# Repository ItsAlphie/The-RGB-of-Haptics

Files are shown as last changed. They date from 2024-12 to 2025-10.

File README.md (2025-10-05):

# The RGB of Haptics: The Impact of Haptic Primary Colours on Texture Perception for Extended Reality
## What's this project about?
This repository contains the code and framework developed for our Master's thesis project at KU Leuven.
The project explores haptic feedback in Extended Reality (XR) through the design and evaluation of a wearable glove prototype. The glove implements the Haptic Primary Color Theory (HPCT), a conceptual model that breaks down tactile sensations into basic "haptic primitives" such as hardness, roughness, and thermal feedback.

By combining these primitives, the glove aims to approximate textures and materials in a way that enhances immersion in XR environments.

## Project Overview

### Hardware: 
A custom-built haptic glove integrating miniaturized actuators (vibro-tactile, thermal, and pressure feedback).

<p float="left">
  
  
  
</p>

### Software: 
A Unity-based VR environment for rendering virtual textures and controlling haptic output. (Unity version 2022.3.58f1)

a39b0428bdcb1dedeffa3c9d26d67ef41e6b70b5

### Framework: 
Wireless communication between the glove's microcontroller and Unity to synchronize haptic feedback with virtual interactions.



### Evaluation:
* User Test 1: Psychophysical identification of base haptic primitives without visual stimuli.
* User Test 2: Material comparison test with real-world analogues to evaluate texture approximation.

## Demo
[🎥 Demo video: Overview & Haptic Demonstration](https://github.com/ItsAlphie/The-RGB-of-Haptics/blob/main/Demo's/Demo_OverviewAndDemonstration.mp4)

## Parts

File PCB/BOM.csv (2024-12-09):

Reference | Value | Datasheet | Footprint | Qty | DNP
C1,C2,C3,C4,C6,C7 | 1µF | ~ | Capacitor_SMD:C_0805_2012Metric_Pad1.18x1.45mm_HandSolder | 6 | lab
C5 | 0.01µF | ~ | Capacitor_SMD:C_0805_2012Metric_Pad1.18x1.45mm_HandSolder | 1 | lab
C8 | 10µF | ~ | Capacitor_SMD:C_0805_2012Metric_Pad1.18x1.45mm_HandSolder | 1 | lab
C9,C10 | 10nF | ~ | Capacitor_SMD:C_0805_2012Metric_Pad1.18x1.45mm_HandSolder | 2 | lab
Flex1 | 20k - 50k | ~ | Connector_PinHeader_2.54mm:PinHeader_1x02_P2.54mm_Vertical | 1
IC1 | MAX1968EUI+T | https://datasheets.maximintegrated.com/en/ds/MAX1968-MAX1969.pdf | SOP65P640X110-28N | 1 | v
J1 | Power | ~ | Connector_PinHeader_2.54mm:PinHeader_1x02_P2.54mm_Vertical | 1 | v
J2 | VIBR1 | ~ | Connector_PinHeader_2.54mm:PinHeader_1x02_P2.54mm_Vertical | 1 | v
J3 | VIBR2 | ~ | Connector_PinHeader_2.54mm:PinHeader_1x02_P2.54mm_Vertical | 1 | v
J4 | Temperature Control & Flex Sensor | ~ | Connector_PinHeader_2.54mm:PinHeader_2x02_P2.54mm_Vertical | 1 | v
J6 | Haptic Motors | ~ | Connector_PinHeader_2.54mm:PinHeader_2x03_P2.54mm_Vertical | 1 | v
L1,L2 | 3.3µH | ~ | Coil_VLS6045:VLS6045 | 2 | v
PE1 | PeltierElement | ~ | Connector_PinHeader_2.54mm:PinHeader_1x02_P2.54mm_Vertical | 1 | v
R1,R4 | 50k | ~ | Resistor_SMD:R_0805_2012Metric_Pad1.20x1.40mm_HandSolder | 2 | lab
R2 | 100k | ~ | Resistor_SMD:R_0805_2012Metric_Pad1.20x1.40mm_HandSolder | 1 | lab
R3 | 50m | ~ | Resistor_SMD:R_1206_3216Metric_Pad1.30x1.75mm_HandSolder | 1 | lab
R5 | 32.5k | ~ | Resistor_SMD:R_0805_2012Metric_Pad1.20x1.40mm_HandSolder | 1 | lab
R6,R7 | 100 | ~ | Resistor_SMD:R_0805_2012Metric_Pad1.20x1.40mm_HandSolder | 2 | lab
TH1 | Thermistor_NTC | ~ | Connector_PinHeader_2.54mm:PinHeader_1x02_P2.54mm_Vertical | 1 | v
U1 | LM358 | http://www.ti.com/lit/ds/symlink/lm2904-n.pdf | LM358:SOP65P640X135-8N | 1 | v
U2,U3 | ~ |  | HapticDriver:DRV2605l | 2 | v

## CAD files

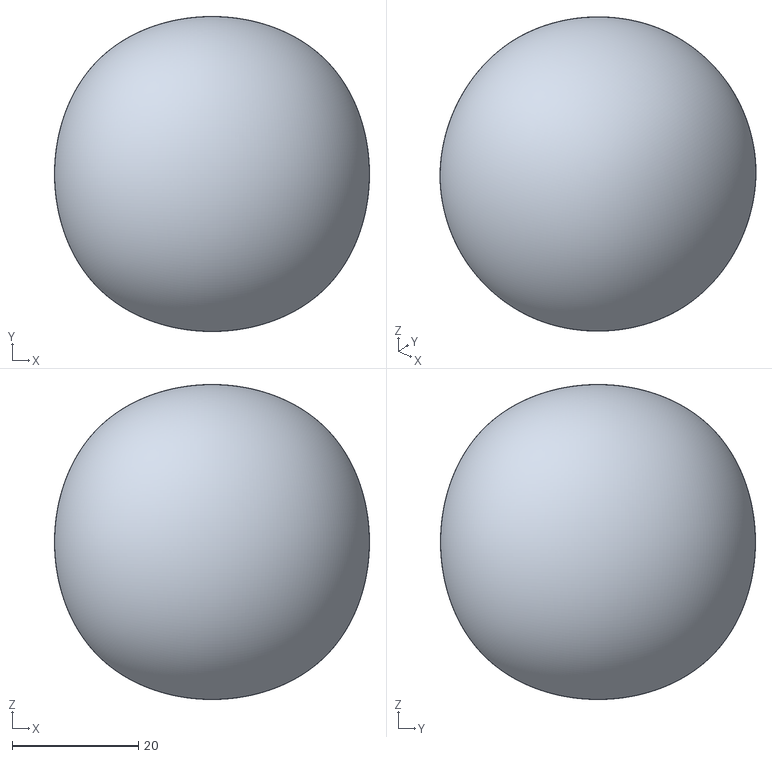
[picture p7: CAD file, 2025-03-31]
HPCT_Unity/Assets/Downloaded/YughuesFreeBarkMaterial/Preview/YFBM_sphere.obj
50.0 x 50.0 x 50.0

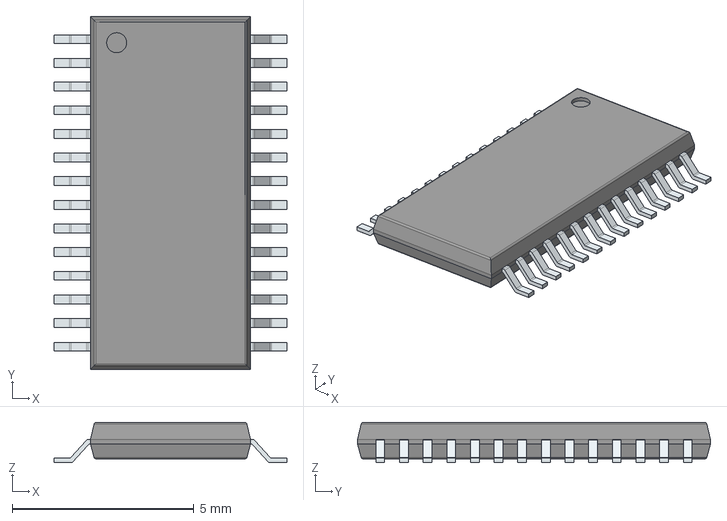
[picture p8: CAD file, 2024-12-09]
PCB/LIB_MAX1968EUI+T/MAX1968EUI+T/3D/MAX1968EUI+T.stp
6.40 x 9.70 x 1.10 mm
PinsArrayLR

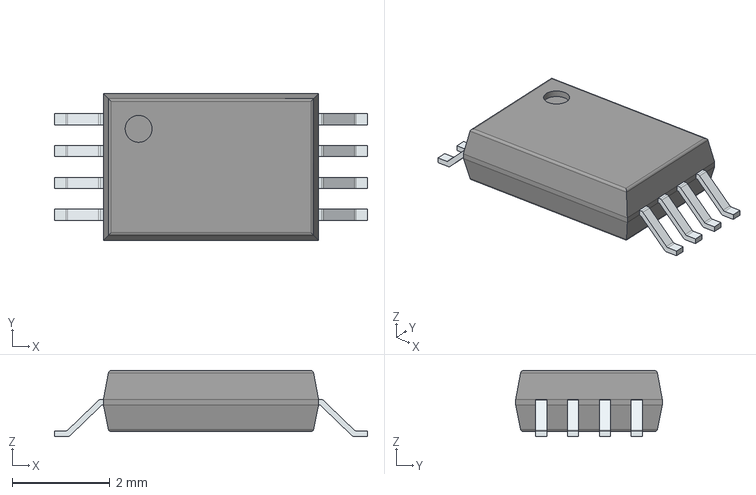
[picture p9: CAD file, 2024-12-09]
PCB/LM358FV-GE2/3D/LM358FV-GE2.stp
6.40 x 3.00 x 1.35 mm
PinsArrayLR

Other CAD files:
PCB/LIB_MAX1968EUI+T/MAX1968EUI+T/Allegro/sop65p640x110-28n.psm
PCB/LIB_MAX1968EUI+T/MAX1968EUI+T/DEHDL/max1968eui_t/chips/chips.prt
PCB/LM358FV-GE2/Allegro/sop65p640x135-8n.psm
PCB/LM358FV-GE2/DEHDL/lm358fv_ge2/chips/chips.prt

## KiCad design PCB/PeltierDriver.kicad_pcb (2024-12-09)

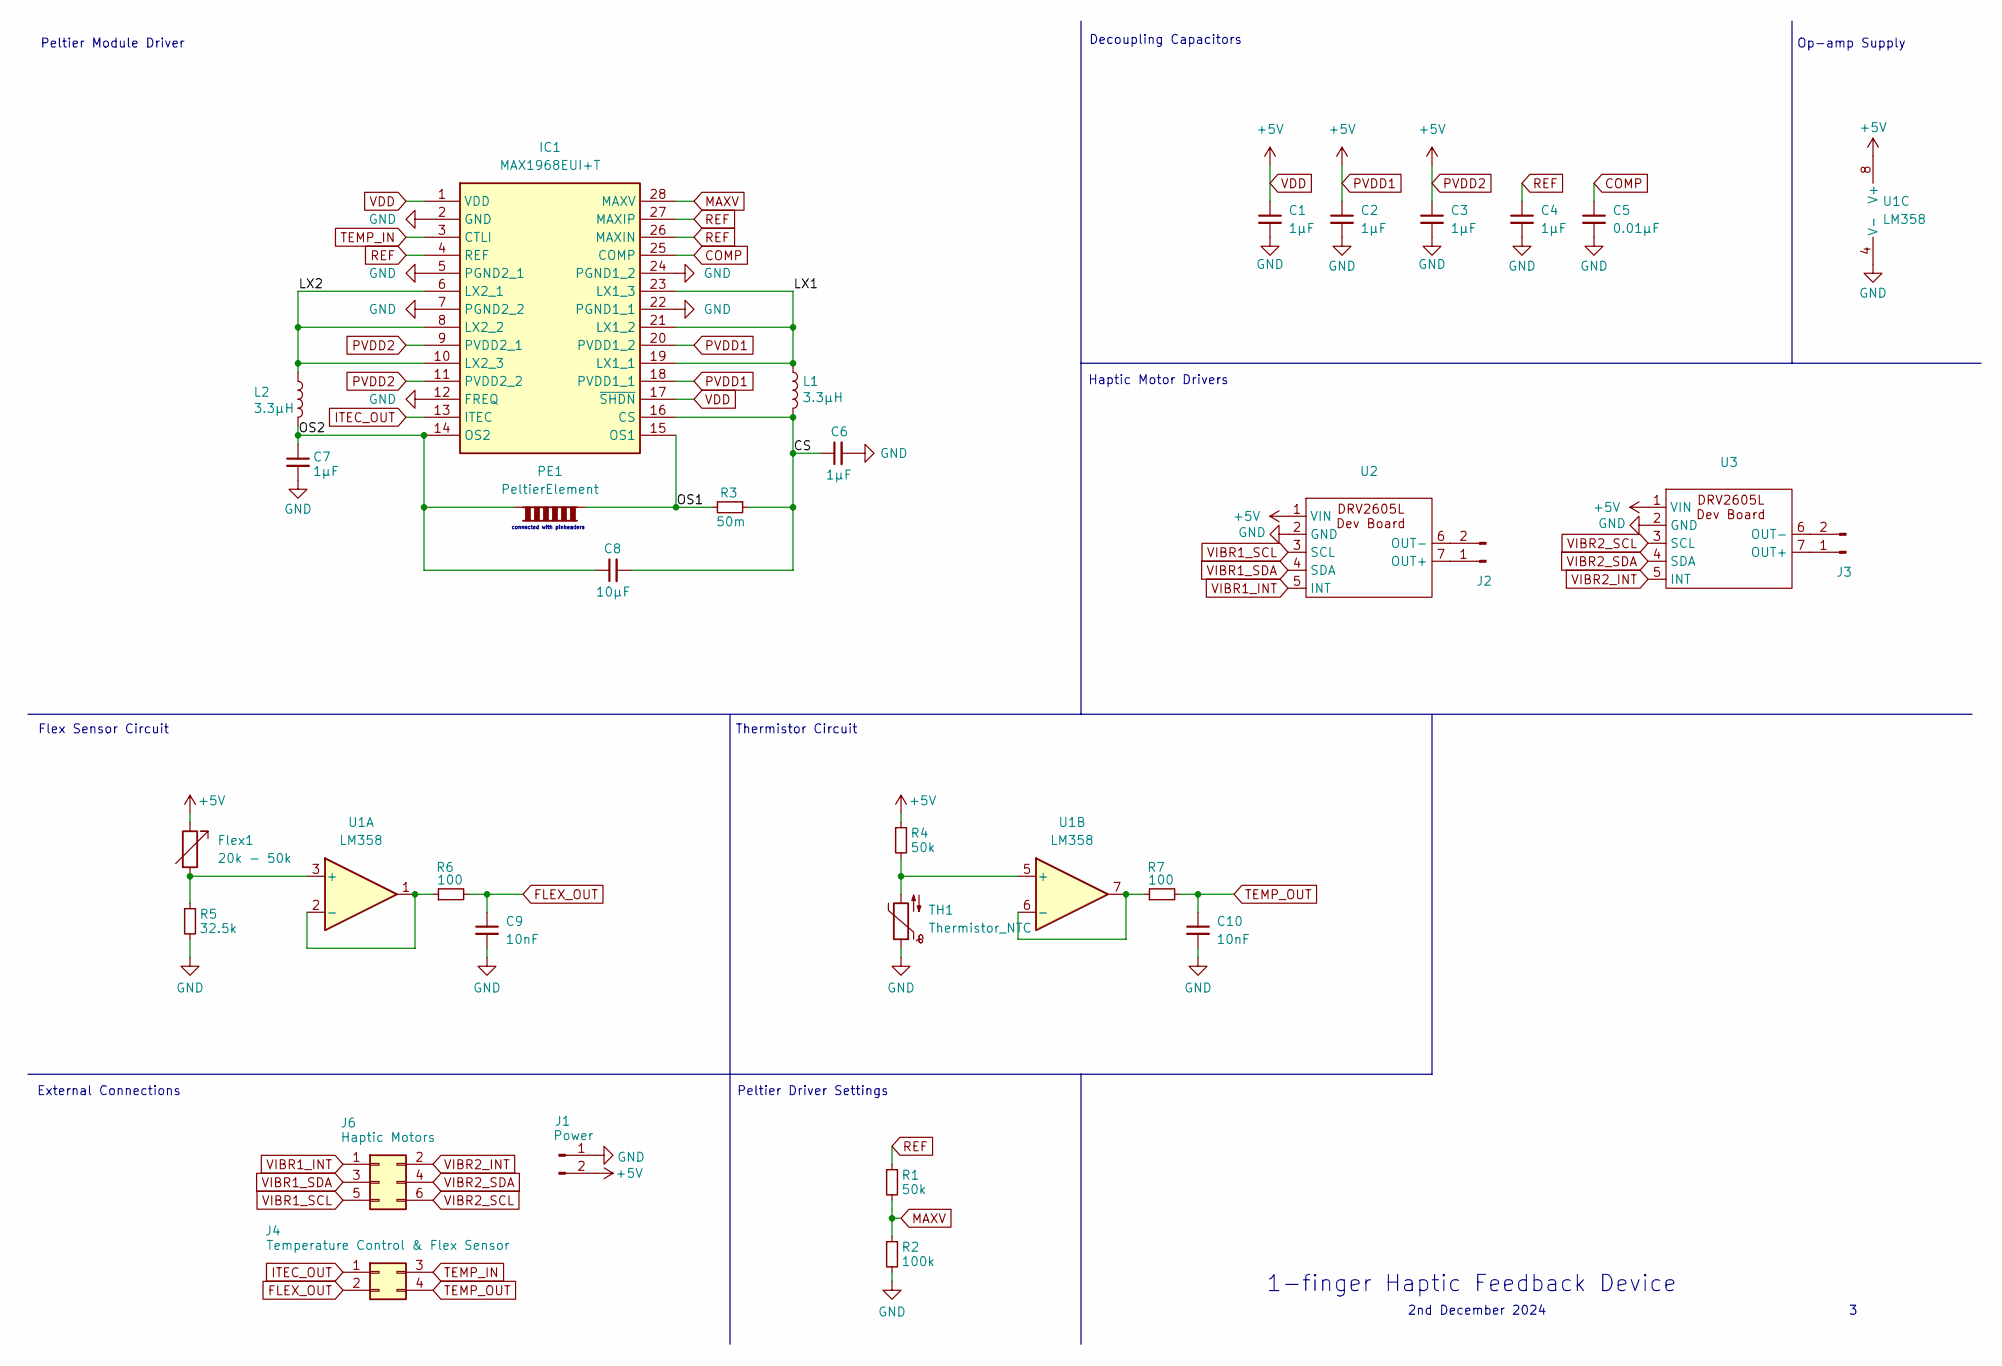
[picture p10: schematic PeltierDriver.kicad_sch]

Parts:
C1, C2, C3, C4, C6, C7: 1µF; C_0805_2012Metric_Pad1.18x1.45mm_HandSolder
C5: 0.01µF; C_0805_2012Metric_Pad1.18x1.45mm_HandSolder
C8: 10µF; C_0805_2012Metric_Pad1.18x1.45mm_HandSolder
C9, C10: 10nF; C_0805_2012Metric_Pad1.18x1.45mm_HandSolder
Flex1: 20k - 50k; PinHeader_1x02_P2.54mm_Vertical
IC1: MAX1968EUI+T; SOP65P640X110-28N; Mouser Part Number 700-MAX1968EUIT
J1: Power; PinHeader_1x02_P2.54mm_Vertical
J2: VIBR1; PinHeader_1x02_P2.54mm_Vertical
J3: VIBR2; PinHeader_1x02_P2.54mm_Vertical
J4: Temperature Control & Flex Sensor; PinHeader_2x02_P2.54mm_Vertical
J6: Haptic Motors; PinHeader_2x03_P2.54mm_Vertical
L1, L2: 3.3µH; VLS6045
PE1: PeltierElement; PinHeader_1x02_P2.54mm_Vertical
R1, R4: 50k; R_0805_2012Metric_Pad1.20x1.40mm_HandSolder
R2: 100k; R_0805_2012Metric_Pad1.20x1.40mm_HandSolder
R3: 50m; R_1206_3216Metric_Pad1.30x1.75mm_HandSolder
R5: 32.5k; R_0805_2012Metric_Pad1.20x1.40mm_HandSolder
R6, R7: 100; R_0805_2012Metric_Pad1.20x1.40mm_HandSolder
TH1: Thermistor_NTC; PinHeader_1x02_P2.54mm_Vertical
U1: LM358; SOP65P640X135-8N
U2, U3: DRV2605l

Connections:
/CS: C6.1, C8.2, IC1.16 (CS), L1.2, R3.1
/LX1: IC1.19 (LX1_1), IC1.21 (LX1_2), IC1.23 (LX1_3), L1.1
/LX2: IC1.6 (LX2_1), IC1.8 (LX2_2), IC1.10 (LX2_3), L2.1
/OS1: IC1.15 (OS1), PE1.1, R3.2
/OS2: C7.1, C8.1, IC1.14 (OS2), L2.2, PE1.2
COMP: C5.1, IC1.25 (COMP)
FLEX_OUT: C9.1, J4.2, R6.2
GND: C1.2, C2.2, C3.2, C4.2, C5.2, C6.2, C7.2, C9.2, C10.2, IC1.2 (GND), IC1.5 (PGND2_1), IC1.7 (PGND2_2), IC1.12 (FREQ), IC1.22 (PGND1_1), IC1.24 (PGND1_2), J1.1, R2.2, R5.2, TH1.1, U1.4 (V-), U2.2 (GND), U3.2 (GND); also elsewhere on the board
ITEC_OUT: IC1.13 (ITEC), J4.1
MAXV: IC1.28 (MAXV), R1.2, R2.1
unnamed 10: J2.1, U2.7 (OUT+); also elsewhere on the board
unnamed 11: J2.2, U2.6 (OUT-); also elsewhere on the board
unnamed 12: J3.1, U3.7 (OUT+); also elsewhere on the board
unnamed 13: J3.2, U3.6 (OUT-); also elsewhere on the board
unnamed: Flex1.2, R5.1, U1.3 (+)
unnamed: R6.1, U1.1, U1.2 (-)
unnamed: R4.2, TH1.2, U1.5 (+)
unnamed: R7.1, U1.6 (-), U1.7
PVDD1: C1.1, C2.1, C3.1, Flex1.1, IC1.1 (VDD), IC1.9 (PVDD2_1), IC1.11 (PVDD2_2), IC1.17 (~SHDN), IC1.18 (PVDD1_1), IC1.20 (PVDD1_2), J1.2, R4.1, U1.8 (V+), U2.1 (VIN), U3.1 (VIN); also elsewhere on the board
REF: C4.1, IC1.4 (REF), IC1.26 (MAXIN), IC1.27 (MAXIP), R1.1
TEMP_IN: IC1.3 (CTLI), J4.3
TEMP_OUT: C10.1, J4.4, R7.2
VIBR1_INT: J6.1, U2.5 (INT); also elsewhere on the board
VIBR1_SCL: J6.5, U2.3 (SCL); also elsewhere on the board
VIBR1_SDA: J6.3, U2.4 (SDA); also elsewhere on the board
VIBR2_INT: J6.2, U3.5 (INT); also elsewhere on the board
VIBR2_SCL: J6.6, U3.3 (SCL); also elsewhere on the board
VIBR2_SDA: J6.4, U3.4 (SDA); also elsewhere on the board

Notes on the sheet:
Thermistor Circuit
Op-amp Supply
connected with pinheaders
External Connections
Peltier Module Driver
Haptic Motor Drivers
Flex Sensor Circuit
Peltier Driver Settings
1-finger Haptic Feedback Device
Decoupling Capacitors
2nd December 2024

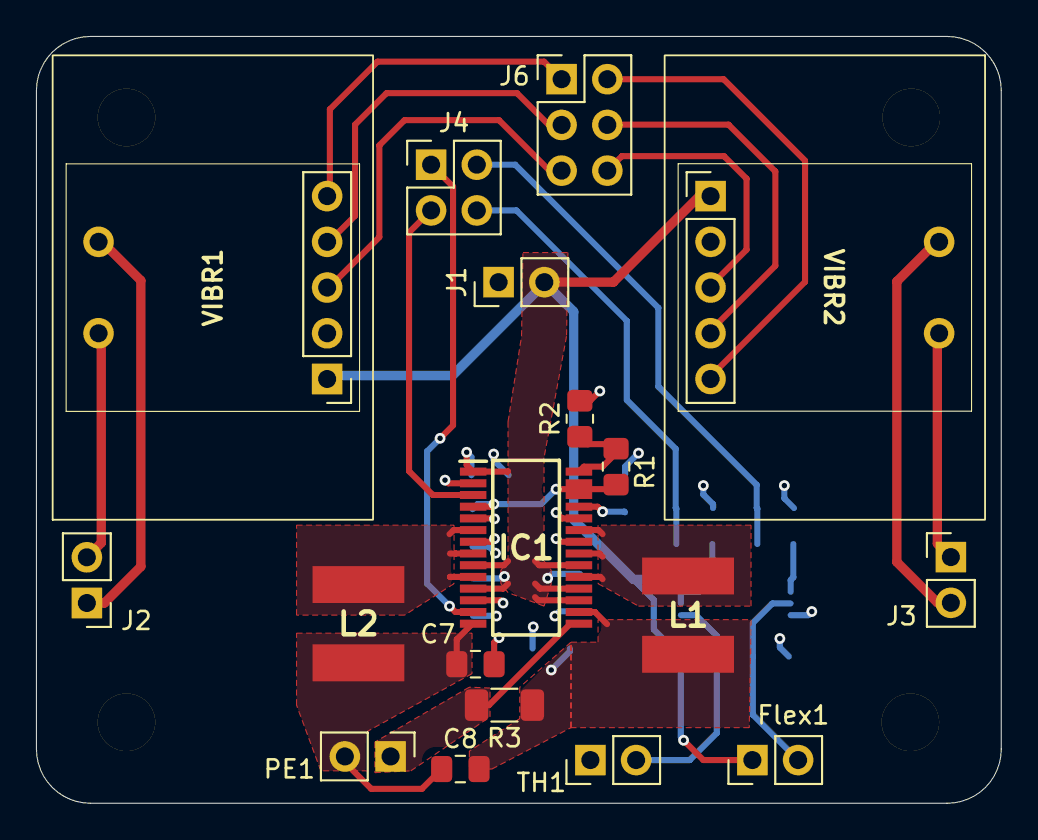
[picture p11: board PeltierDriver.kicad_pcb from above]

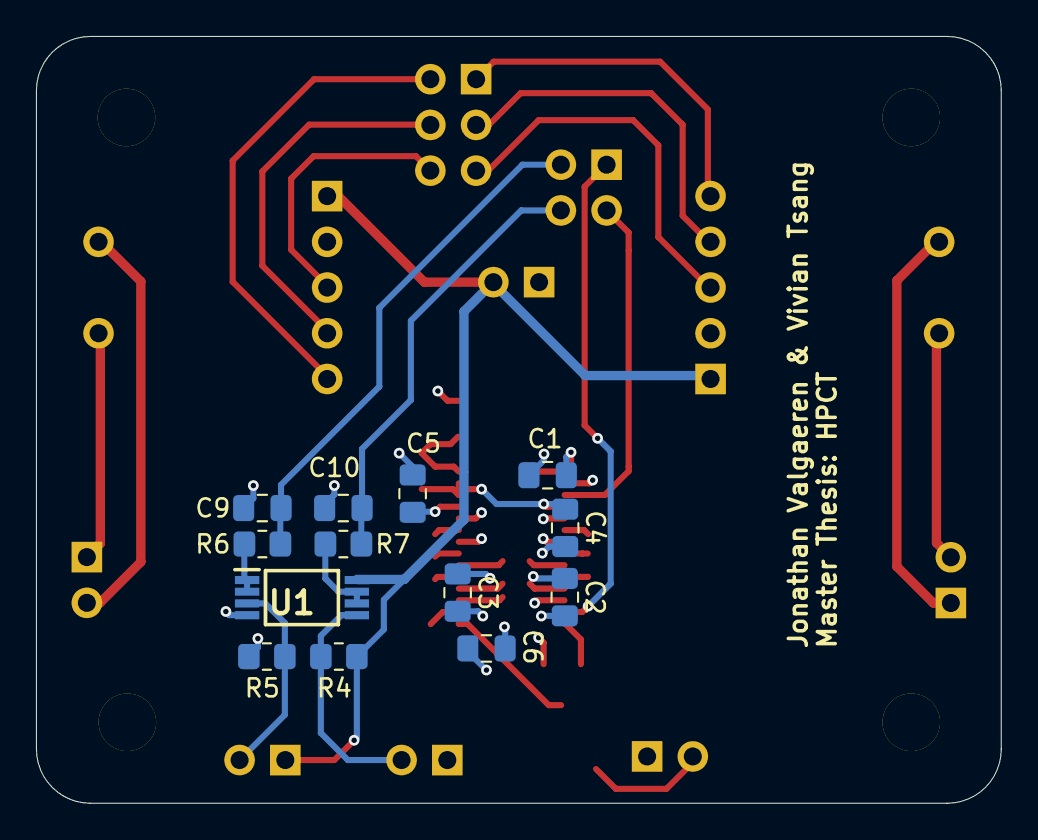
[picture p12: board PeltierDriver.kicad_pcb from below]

Board: 4 copper layers, 53.6 x 42.6 mm, 31 parts (13 on the bottom side), 28 nets.

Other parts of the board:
VIBR1, VIBR2: DRV2605l

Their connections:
GND: VIBR1.2 (GND), VIBR2.2 (GND); also elsewhere on the board
unnamed 10: VIBR1.7 (OUT+); also elsewhere on the board
unnamed 11: VIBR1.6 (OUT-); also elsewhere on the board
unnamed 12: VIBR2.7 (OUT+); also elsewhere on the board
unnamed 13: VIBR2.6 (OUT-); also elsewhere on the board
PVDD1: VIBR1.1 (VIN), VIBR2.1 (VIN); also elsewhere on the board
VIBR1_INT: VIBR1.5 (INT); also elsewhere on the board
VIBR1_SCL: VIBR1.3 (SCL); also elsewhere on the board
VIBR1_SDA: VIBR1.4 (SDA); also elsewhere on the board
VIBR2_INT: VIBR2.5 (INT); also elsewhere on the board
VIBR2_SCL: VIBR2.3 (SCL); also elsewhere on the board
VIBR2_SDA: VIBR2.4 (SDA); also elsewhere on the board

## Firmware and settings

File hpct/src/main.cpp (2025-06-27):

#include <Wire.h>
#include "vibration.h"
#include <Arduino.h>
#include <ESP32Servo.h>
#include "peltiercontroller.h"
#include <WiFi.h>
#include <WiFiUdp.h>

// ------------------------- WIFI -----------------------------
// https://github.com/m5stack/azure_iothub_arduino_lib_esp32/blob/master/hardware/espressif/esp32/libraries/WiFi/examples/WiFiUDPClient/WiFiUDPClient.ino 
// WiFi credentials
// #define ssid "Redmi"         // Replace with your WiFi SSID
// #define password "galagala"           // Replace with your WiFi password

#define ssid "Hotspot"         // Replace with your WiFi SSID
#define password "eeeeeeee"           // Replace with your WiFi password

// Server settings
#define serverIP "192.168.245.91"      // Unity server's IP address  
#define serverPort 11000             // Unity server's port


WiFiUDP udp;
char incomingPacket[64];  // Buffer to hold incoming message

int command;
int parameter_0;
int parameter_1;
int parameter_2;


// ------------------------- HARDWARE -----------------------------
Vibration vibration;

Servo servoMotor;
// int pos = 0;

PeltierController peltierController(4,6,1,1);

// Flex sensor
int flexPin = 2;
bool flexEnabled = false;

// -----------------------------------------------------------------
TaskHandle_t TemperatureAndFlexControlTask;


void connectWifi(){
  WiFi.begin(ssid, password);

  while (WiFi.status() != WL_CONNECTED) {
    delay(500);
    Serial.print(".");
  }

  Serial.println("");
  Serial.println("WiFi connected.");
  Serial.println("IP address: ");
  Serial.println(WiFi.localIP());
  udp.begin(serverPort);
}

void sendMessage(float message){
  // char buffer[10];
  // sprintf (buffer, "%d", message);
  String buffer = String(message);
  udp.beginPacket(serverIP, serverPort);
  udp.print(buffer);
  udp.endPacket();
}


void sendFlexValue(){
  float flexValue= analogRead(flexPin) * (3.3f / 4095.0f);;
  sendMessage(flexValue);
  Serial.print("Flex Value is: ");
  Serial.println(flexValue);
}

void temperatureAndFlexControl(void * pvParameters){
  while(1){
      if(peltierController.isEnabled()){
        peltierController.temperatureControl();
      }
  // if(flexEnabled){
  //     sendFlexValue();
  // }
  vTaskDelay(1000);
  }
}

const char * receiveMessage() {
  int packetSize = udp.parsePacket();  // Check for an incoming UDP packet
  if (packetSize) {
    
    int len = udp.read(incomingPacket, 255);
    if (len > 0) {
      incomingPacket[len] = '\0';  // Null-terminate the string
    }
    Serial.print("Received: ");
    Serial.println(String(incomingPacket));
    return incomingPacket;  // Return as a String
  }
  return "";  // Return an empty String if no message was received
}

void setup() {

  Serial.begin(9600);
  connectWifi();

  xTaskCreatePinnedToCore(
                temperatureAndFlexControl,   /* Task function. */
                "TemperatureAndFlexControl",     /* name of task. */
                3000,       /* Stack size of task */
                NULL,        /* parameter of the task */
                0,           /* priority of the task */
                &TemperatureAndFlexControlTask,      /* Task handle to keep track of created task */
                0);          /* pin task to core 1 */
  delay(500);

  servoMotor.attach(19); 



  vibration.init();

  peltierController.setDesiredTemp(30);

  Serial.print("Free heap: ");
Serial.println(ESP.getFreeHeap());


}
  
void loop() {
  // ------------------------- VIBRATION -----------------------------

  // vibration.setFrequency(0, 10);
  // vibration.setStrength(0, 255);
  // vibration.enable(0);
  // vibration.disable(1);
  // delay(3000);
  // vibration.setFrequency(0, 3);
  // vibration.setStrength(0, 125);
  // // vibration.disable(0);
  //   vibration.enable(0);

  // vibration.enable(1);
  // delay(3000);

  // ------------------------- SERVO -----------------------------

  // for (pos = 0; pos <= 180; pos += 1) { // goes from 0 degrees to 180 degrees
  //   // in steps of 1 degree
  //   servoMotor.write(pos);              // tell servo to go to position in variable 'pos'
  //   delay(15);                       // waits 15ms for the servo to reach the position
  // }
  // for (pos = 180; pos >= 0; pos -= 1) { // goes from 180 degrees to 0 degrees
  //   servoMotor.write(pos);              // tell servo to go to position in variable 'pos'
  //   delay(15);                       // waits 15ms for the servo to reach the position
  // }

  // ------------------------- PELTIER -----------------------------
  // peltierController.enable();


  // if (peltierController.isEnabled()){
  //     peltierController.temperatureControl();
  // }

// ------------------------- UDP COMM -----------------------------

/* 
  * Stop: 0,0,0,0

  * Set: 1,%d,%d,%d
    - desired temperature [20-40]
    - Titan haptic motor 1: set strength [0-255] (impact)
    - Titan haptic motor 2: set strength [0-255]

  * Continuous: 2,%d,%d,$d
    - Titan haptic motor 1: set frequency [0-100]
    - Titan haptic motor 2: set frequency [0-100]
    - Servo angle [0-180] 
*/

  if(sscanf(receiveMessage(), "%d,%d,%d,%d",&command, &parameter_0, &parameter_1, &parameter_2) ==4){
    switch(command){
      case 0:
        peltierController.setDesiredTemp(25);
        vibration.disable(0);
        vibration.disable(1);
        servoMotor.write(90);

        break;

      case 1: // Initial haptic activation before any user movement. Only sent once.
        
        peltierController.enable();
        peltierController.setDesiredTemp(parameter_0);

        vibration.setStrength(0, parameter_1);
        vibration.setStrength(1, parameter_2);
        
        break;
      
      case 2: // Adapt haptic parameters to user's movement. Sent continuously.

        // Set frequency to 0 if within 1-2 Hz range (3 Hz is minimum frequency)
        if(parameter_0 > 0 && parameter_0 < 3){parameter_0 = 0;}
        if(parameter_1 > 0 && parameter_1 < 3){parameter_1 = 0;}

        vibration.setFrequency(0, parameter_0);
        vibration.setFrequency(1, parameter_1);
        servoMotor.write(parameter_2);

        break;

      default:
        Serial.println("Incorrect input");
        break;
    }
  }

}

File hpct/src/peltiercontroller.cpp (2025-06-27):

#include "peltiercontroller.h"

PeltierController::PeltierController(int pPin1, int pPin2, int thPin, int KpVal) : peltierDriverPin1{pPin1}, peltierDriverPin2{pPin2}, thermistorPin{thPin}, Kp{KpVal}
{
    pinMode(thermistorPin, INPUT);
    pinMode(peltierDriverPin1, OUTPUT);
    pinMode(peltierDriverPin2, OUTPUT);

    analogReadResolution(12);
}

void PeltierController::setDesiredTemp(int temp)
{
    desiredTemp = temp;
}

void PeltierController::temperatureControl()
{
    readThermistor();
    calculateError();
    // int output = error * Kp; no pid control for now
    if(desiredTemp == 25){
            disable();
        }
    else{
        if (error > 3)
    { 
        Serial.println("Temperature too low. Heating up.");
        digitalWrite(peltierDriverPin1, HIGH);
        digitalWrite(peltierDriverPin2, LOW);
    }
    else if (error < -3)
    {
        Serial.println("Temperature too high. Cooling down.");
        digitalWrite(peltierDriverPin1, LOW);
        digitalWrite(peltierDriverPin2, HIGH);
    }
    else
    {
        Serial.println("Within desired temperature range.");
        digitalWrite(peltierDriverPin1, LOW);
        digitalWrite(peltierDriverPin2, LOW);
    }
    }
    
    Serial.println("------");
}

void PeltierController::readThermistor()
{
    float voltage = analogRead(thermistorPin) * (3.3f / 4095.0f); 
    Serial.print("Current voltage read: ");
    Serial.println(voltage);

    float thermistorValue = - (10000.0f*voltage)/(voltage - 5.0f);
    Serial.print("Current thermistor read: ");
    Serial.println(thermistorValue);
    
    currentTemp = interpolate(thermistorValue);
    Serial.print("Current temperature: ");
    Serial.println(currentTemp);
}

float PeltierController::interpolate(float resistanceValue)
{
    for (int i = 0; i < POINTS - 1; i++)
    {
        if (resistanceValue <= rt_array[i] && resistanceValue >= rt_array[i + 1])
        {
            return (temp_array[i] + (resistanceValue - rt_array[i]) *
                                        (temp_array[i + 1] - temp_array[i]) /
                                        (rt_array[i + 1] - rt_array[i]));
        }
    }
    return -999;
}

void PeltierController::calculateError()
{
    error = desiredTemp - currentTemp;
    Serial.print("Error is: ");
    Serial.println(error);
}

void PeltierController::enable()
{
    Serial.println("Peltier element enabled");
    enabled = true;
}

void PeltierController::disable()
{
    enabled = false;
    Serial.println("Peltier element disabled");
    digitalWrite(peltierDriverPin1, LOW);
    digitalWrite(peltierDriverPin2, LOW);
}

bool PeltierController::isEnabled()
{
    return enabled;
}

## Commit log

2024-12-09 Added test code and PCB design
    [BOM.csv, EDI2CAP.CFG, LM358FV-GE2.SchLib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]
2024-12-09 Added servo test code and renamed vibration haptics file
    [Vibartion.ino]
2025-02-12 Added protoboard and vibration ino file
    [Untitled Sketch.fzz]
2025-02-16 Created first iteration of unity testing game + demo video
    [thry_editor_locale.csv, thry_locale_example.csv]
2025-02-19 Added dual I2C bus test code + put arduino code in folders (required by IDE)
2025-02-19 Added experimental (read failed) Dual I2C channels code
    [DualI2C.ino]
2025-02-19 Added microcontroller protoboard design
    [MainBoard.fzz, Microcontroller.fzz]
2025-02-23 ESP32 code without Unity communication
2025-02-26 Added Finger Tracking on Hand in Unity
    [thry_editor_locale.csv, thry_locale_example.csv]
2025-02-28 Added Communication script and updated fingertracking script
2025-02-28 Bug fix: wrong initiation of communication thread and socket
2025-02-28 Added colliders to finger & test objects
2025-03-02 Reorganised Unity Folders, added foundation for material presets, added basic Material/Finger collision Interaction
2025-03-10 Added test buttons for material tuning
2025-03-11 Updated finger sensor processing
2025-03-11 fixed peltier and flex sensor
    [main.cpp, peltiercontroller.cpp]
2025-03-17 changed udp communication and correcting bugs
    [main.cpp, peltiercontroller.cpp, vibration.cpp]
2025-03-28 Added XR device Simulator
2025-03-28 Added survey questions for the material tests
2025-03-31 Added wood materials
    [YFBM_sphere.obj]
2025-03-31 Changes to MaterialTests and fixed water bowl collider
2025-04-02 Implemented hardness changing in stages
2025-04-02 Changes to scenes
    - fixed vive tracker orientation
    - fixed ending game after quitting material scene
2025-04-02 Fixed velocity stages
2025-04-14 Added materials for testing
2025-04-15 Updates to temperature and vibration control
2025-04-29 changes to temperature range
2025-06-27 Temperature value updates during testing + update to gitignore
2025-07-02 add left/right labels for material test objects
2025-07-02 all options of the material tests now visible without scroll
2025-07-10 temperature range between 15-35 deg
2025-08-05 Fixed tracking in material test + renamed tracker object
2025-08-05 Added outline to left/right labels in material test
2025-08-06 Changes to material parameters
2025-08-18 added hand physics for material tests
2025-08-18 Revert "added hand physics for material tests"
    This reverts commit a4f37a1490253da58d7459f221eea17246dcd39a.

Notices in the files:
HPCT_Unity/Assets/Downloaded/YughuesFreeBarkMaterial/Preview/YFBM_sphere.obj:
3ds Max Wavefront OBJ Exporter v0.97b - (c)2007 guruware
